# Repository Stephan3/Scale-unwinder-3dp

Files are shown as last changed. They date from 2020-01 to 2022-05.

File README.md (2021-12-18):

# Scale-unwinder-3dp
A ESP32 driven Scale, Adjustable spoolwidth, esp touch for tare, offset 1, offset 2

For my recuring plates i need to know the remaining Filamet on spool. 
As my wife was yellin a ton for taking away her kitchen scale every day, this here became my solution.

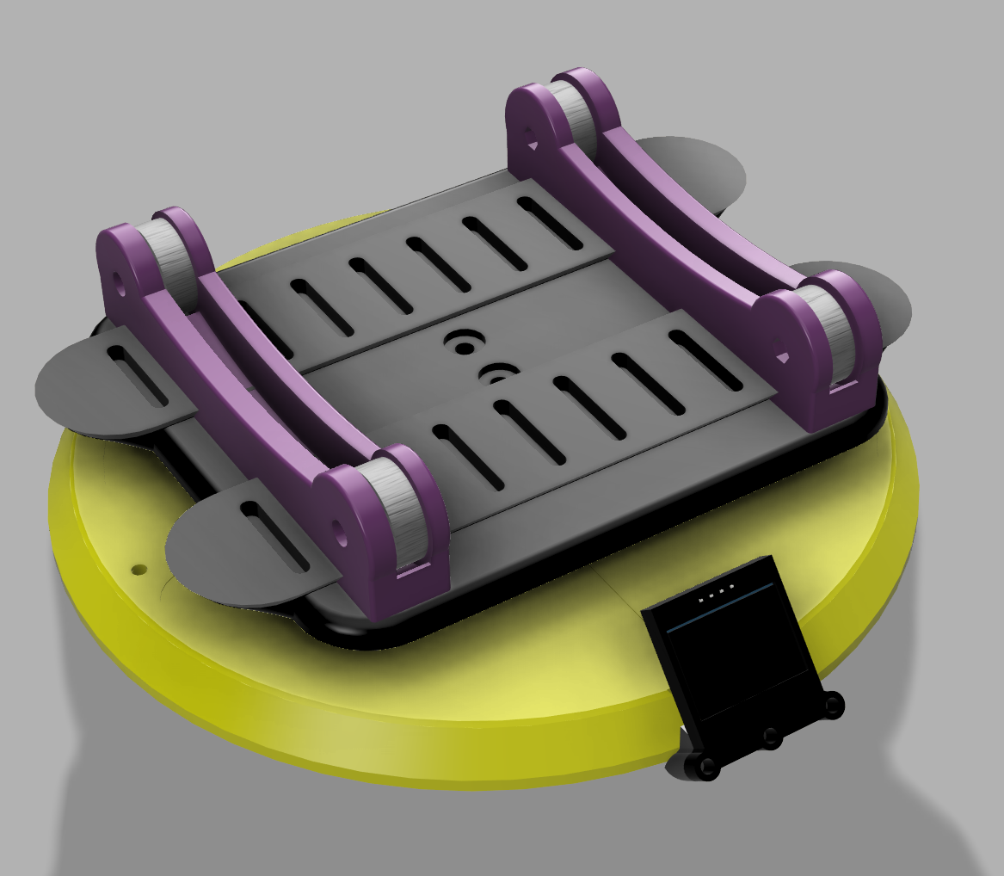
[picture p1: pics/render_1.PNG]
render


You can hardcode two offsets(empty spoolweights) and select them by touching the screws below the display.

### Components used:
Bearings 608RS - [Amazon](https://www.amazon.de/gp/product/B00WXDAUQG/)

A ESP32 mcu - [Aliexpress](https://de.aliexpress.com/item/32839344778)

20KG HX711 Loadcell - [Amazon](https://www.amazon.de/ILS-Module-Aluminum-Weighing-Arduino/dp/B0768CN3T9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)

128x64 OLED LCD - [Amazon](https://www.amazon.de/AZDelivery-Display-Arduino-Raspberry-gratis/dp/B074N9VLZX/ref=sr_1_5?__mk_de_DE=ÅMÅŽÕÑ&keywords=OLED+arduino&qid=1578851947&sr=8-5)

Wires

M3 screws DIN 912 (M3x12mm)

M3 screws DIN 912 (M3x16mm)

M5 screws DIN 912 (M5x20mm)

M4 screws DIN 912 (M4x20mm)

Heatinserts m3 thread  (M3 x 5mm x 4mm)

usbcable

### printsetings
Print in ABS - 
0.2 Layerheigth - 
4.5 Walls - 
50% infill - 
no Supports

### Putting things togeter
See the pictures in pics folder.

Insert the heatinserts with a soldering iron. Use washers between loadcell and scalecase.

Test the touch wires before closing the case, there is a serial feedback. The wires can be pushed into the screw holes of the displayfeet and then just screw in the display holder. You might want to change touchpins T0-T9 (line 72)

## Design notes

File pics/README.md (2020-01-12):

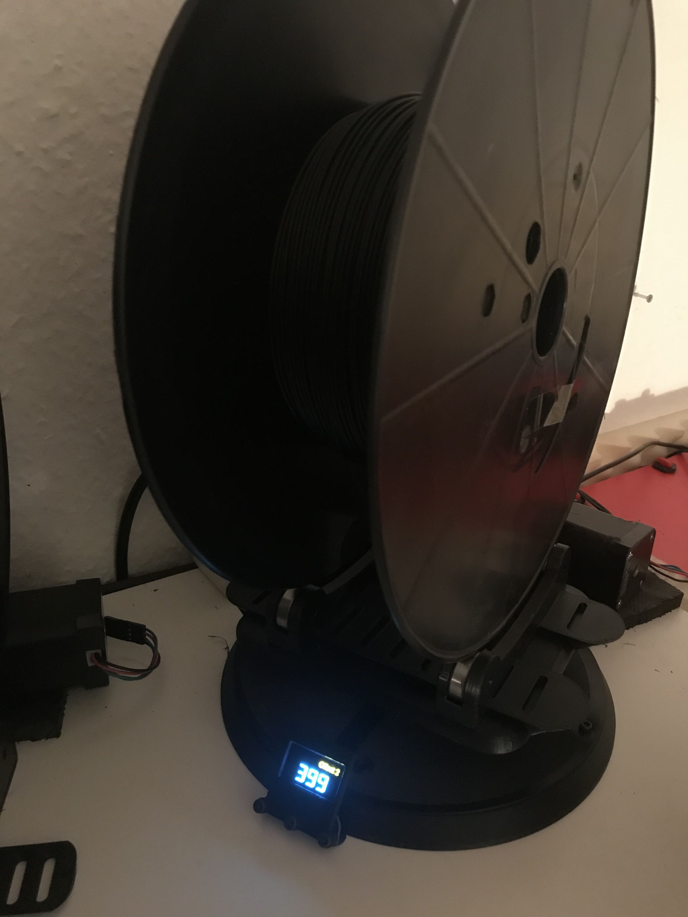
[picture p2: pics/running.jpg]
running

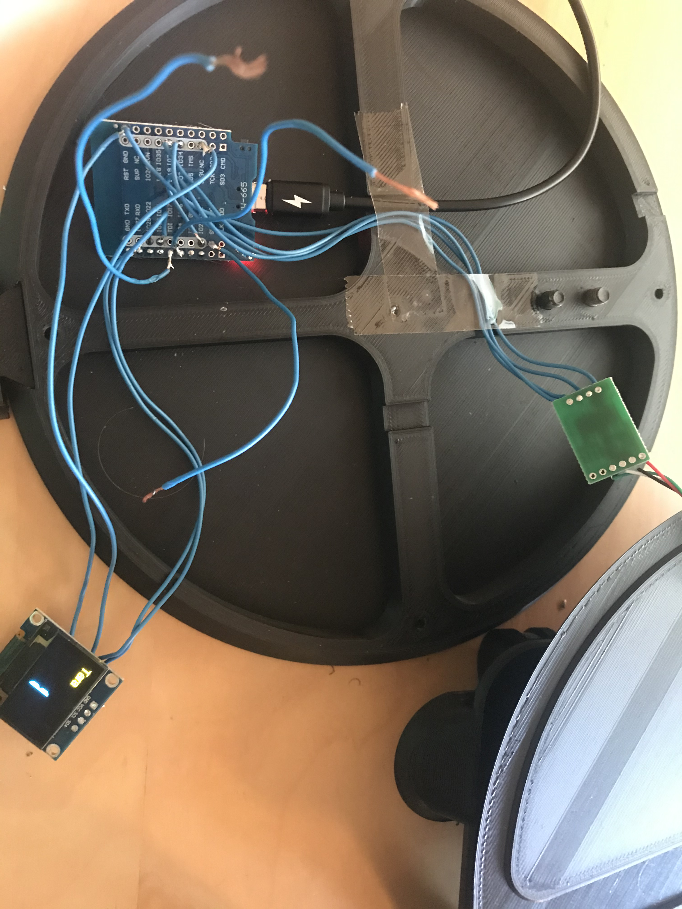
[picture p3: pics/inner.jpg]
inner

render
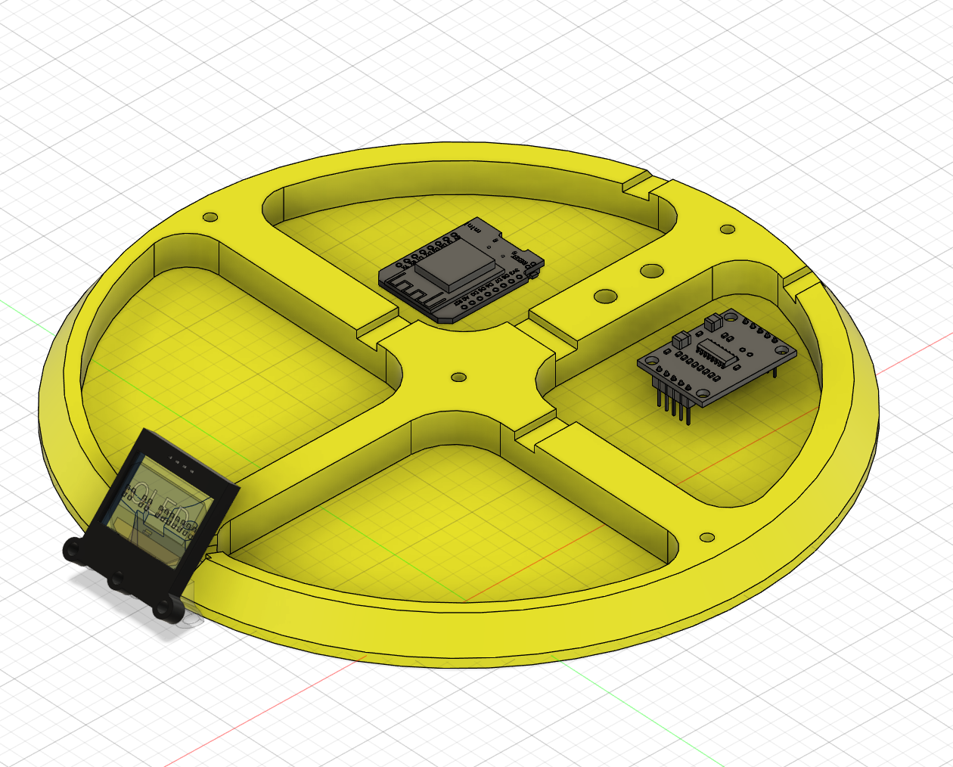
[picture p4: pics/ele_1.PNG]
ele


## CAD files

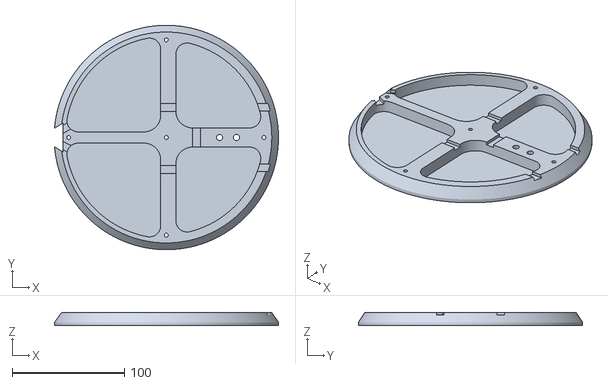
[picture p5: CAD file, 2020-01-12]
STLs/1x_main_body.stl
199.7 x 200.0 x 12.0

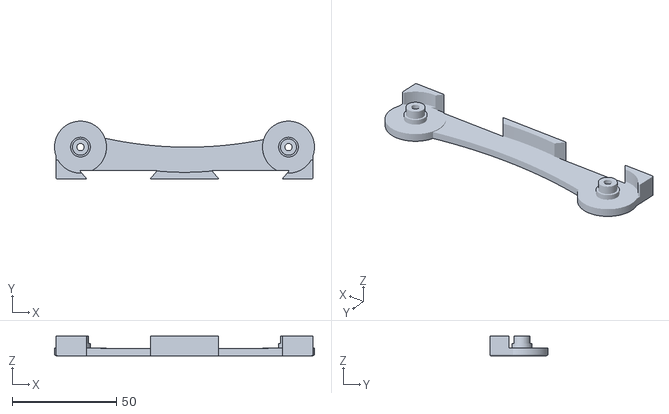
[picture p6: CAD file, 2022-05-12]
STLs/2x_spoolcarrier_b.stl
125.0 x 27.8 x 9.40

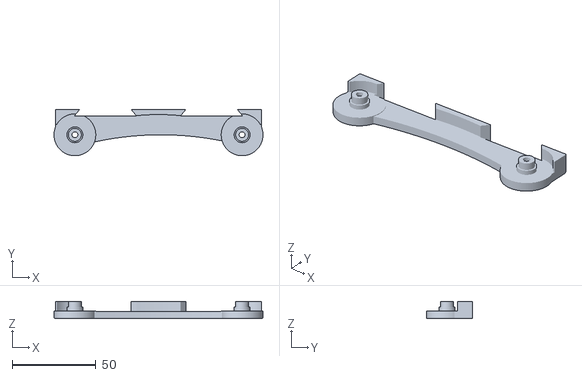
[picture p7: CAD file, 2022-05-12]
STLs/2x_spoolcarrier_a.stl
125.0 x 27.8 x 10.4

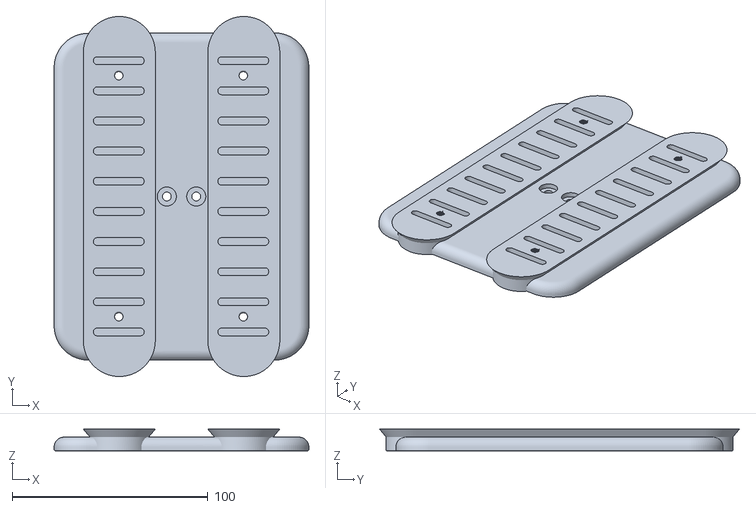
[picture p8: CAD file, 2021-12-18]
STLs/1x_platform.stl
130.0 x 183.7 x 11.1

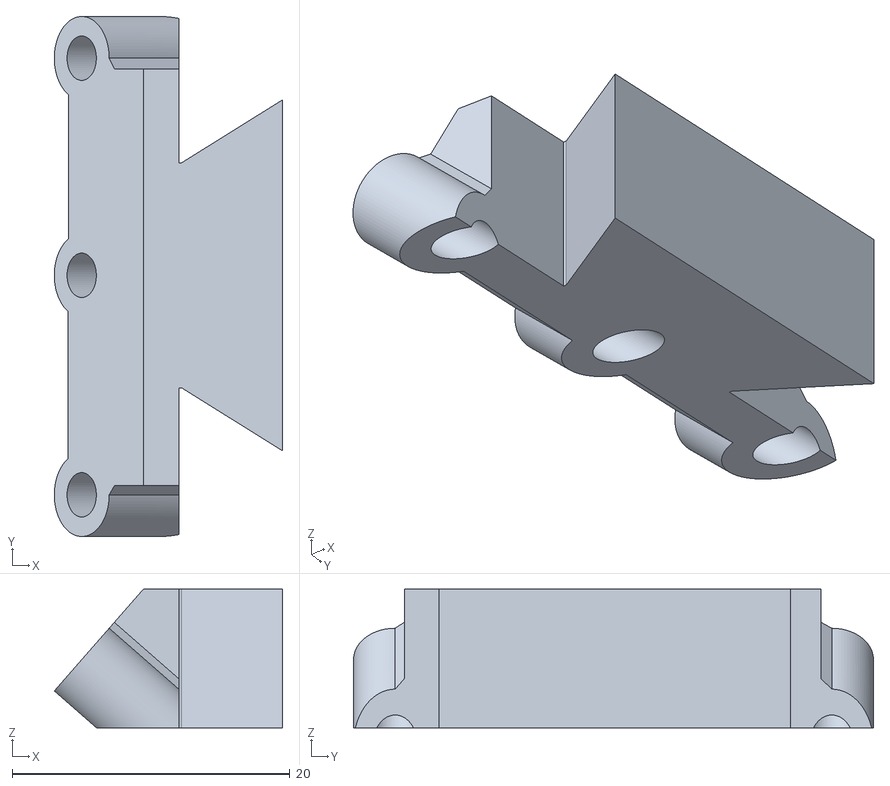
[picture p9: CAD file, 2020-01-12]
STLs/1x_display_feet.stl
16.4 x 37.4 x 10.0

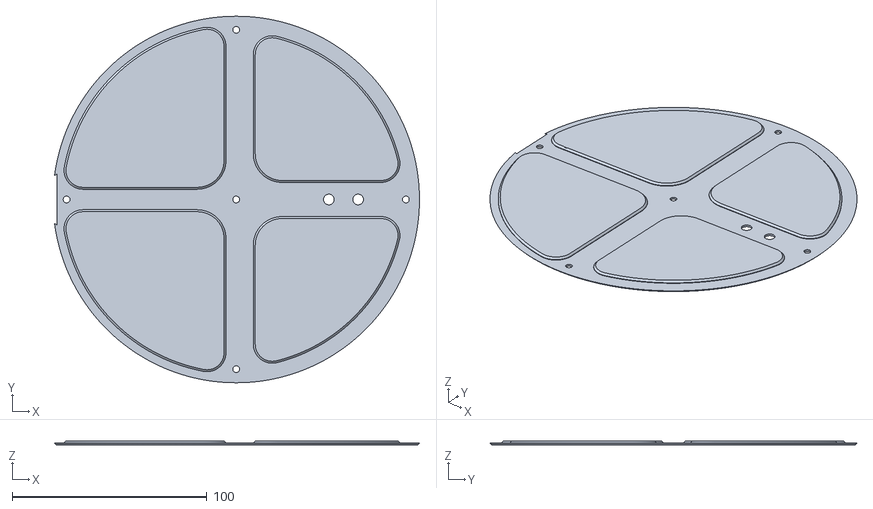
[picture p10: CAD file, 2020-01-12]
STLs/1x_cover.stl
187.2 x 188.0 x 2.25

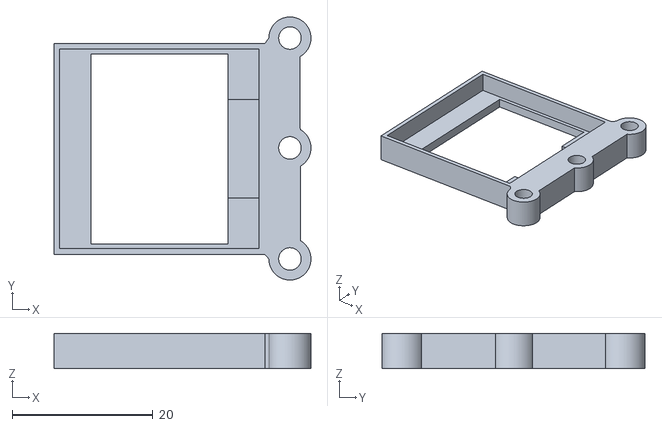
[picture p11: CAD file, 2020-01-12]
STLs/1x_display_body.stl
36.6 x 37.4 x 5.00

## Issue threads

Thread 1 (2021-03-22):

What's the Error?

gb505329191, 2021-03-22:
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
Build the .ino file is error,How to solve it？Thanks！

Stephan3, 2021-03-22:
You are missing a font in your installation.

gb505329191, 2021-03-22:
> 您在安装中缺少字体。

How to solve it？Thanks！

Stephan3, 2021-03-22:
Please google that font and how to install

gb505329191, 2021-03-22:
> Please google that font and how to install

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
what do you think I should go for?

gb505329191, 2021-03-22:
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
The font is now installed, but the compilation is still wrong.

gb505329191, 2021-04-03:
> Please google that font and how to install

Can you send a DSEG14Font document here?Thank you very mach!

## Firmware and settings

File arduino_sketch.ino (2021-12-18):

/*
 * Loadcell messures - .9 lcd output - esptouch
 * 
 */

//#include <ESP8266WiFi.h> // No wifi yet? webapi for current weight?
//#include <Wire.h>  // Only needed for Arduino 1.6.5 and earlier
#include "SSD1306Wire.h"
#include <HX711.h>

// Initialize the OLED display using Wire library
SSD1306Wire  display(0x3c, 21, 22);                         //  OLED wired to 21 and 22
HX711 scale;
volatile bool tare_me = false;

//  touch
const int touch_threeshold = 30;                            //  30 worked well with my screws, adjust here if needed
volatile unsigned long sinceLastTouch = 0;

//  smoothing of weight, less jumpy (exponential smoothening)
float alpha = .6;
float smooth_weight = 0;

//  offsets                                                 //  ofsets set by screw touches
volatile float offset = 0;
const float offset_1 = 234;                                 //  esun ABS+ spools
const float offset_2 = 420;                                 //  my custom 3kg spools

////////////////////////////////////////////////////////
//
////////////////////////////////////////////////////////

int digits(int in_) {

  String in_to_str = String(in_);
  int out_ = 5 - in_to_str.length();
  
  return out_;
}

void gotTouch1(){
  if (millis() - sinceLastTouch < 500) return;
  sinceLastTouch = millis();
  
  Serial.println("Button_1 pressed");
  delay(100);
  offset = 0;
  tare_me = true;
}

void gotTouch2(){
  if (millis() - sinceLastTouch < 500) return;
  sinceLastTouch = millis();
  
  Serial.println("Button_2 pressed");
  delay(100);
  offset = offset_1;
}

void gotTouch3(){
  if (millis() - sinceLastTouch < 500) return;
  sinceLastTouch = millis();
  
  Serial.println("Button_3 pressed");
  delay(100);
  offset = offset_2;
}

//
void setup() {

  Serial.begin(115200);

  display.init();
  display.flipScreenVertically();

  touchAttachInterrupt(T0, gotTouch1, touch_threeshold);
  touchAttachInterrupt(T3, gotTouch2, touch_threeshold);
  touchAttachInterrupt(T5, gotTouch3, touch_threeshold);
  
  scale.begin(19, 23);
  delay(250);
  scale.set_scale(132.f); // this value is obtained by calibrating the scale with known weights; see the README for details
  delay(250);
  scale.tare();
}

void loop() {

  if(tare_me){
    display.clear();
    display.display();
    tare_me = false;
    scale.tare();
  }

  smooth_weight = alpha * scale.get_units(4) + (1-alpha) * smooth_weight; 
  disp_out(smooth_weight-offset);

}

void disp_out(int weight) {
  display.clear();

  //  tare? esun? bigspools?
  display.setFont(ArialMT_Plain_16);
  if( offset == offset_1 ){
    display.drawString(40, 0, "Offset 1");
  } else if ( offset == offset_2 ) {
    display.drawString(75, 0, "Offset 2");
  } else {
    display.drawString(0, 0, "Tara"); 
  }

  //  weight display
  int d_ = digits(weight);
  display.setFont(DSEG14_Classic_Bold_36);
  display.drawString(d_*12, 22, (String)weight);
  
  display.display();
}

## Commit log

2021-12-18 Version bump, now fits esun ABS+ 2.5 spools better. No it has threaded inserts, a voroner has some.
    [1x_platform.stl, 2x_spoolcarrier_a.stl, 2x_spoolcarrier_b.stl]
2022-05-12 fix orientation, sorry defib :D
    [2x_spoolcarrier_a.stl, 2x_spoolcarrier_b.stl]
